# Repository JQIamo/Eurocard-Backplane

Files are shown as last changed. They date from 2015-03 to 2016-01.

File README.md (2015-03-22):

# Eurocard-Backplane

A customized backplane for the JQI Eurocard racks.

This repository also includes a "starter" schematic/board for compliant modules: `EurocardModule.*` Simply copy and paste this into your project folder (or re-save with a different name into your project), and you're off to the races!

## JQI Eurocard standard

We have made our backplane standard compliant with the Toptica backplane -- ie, Toptica modules should work in the JQI rack (and vice versa). However, double-check to make sure there aren't conflicting GPIO signal lines!

Compliant modules should follow the backplane standard (see link below to backplane pinout, or check out the starter schematic in this repository). Here are a few other guidlines that should be followed when designing new modules:

* You are responsible for regulating down from `+/-15V` to the voltages you need.
* De-couple your module from the backplane power traces (eg, with a ferrite bead); be careful about introducing additional noise.
* The standard power supply should provide ~ 7 (?) amps of current to the rack at both `+15V` and `-15V`
* If you need higher voltages, use the HV line.
* The backplane will be (!) equipped with a microcontroller and `WIZNET` ethernet adapter.
* SPI chip-select lines (`SPI_CS`) are routed to individual modules (ie, not tied together on the back plane). If you want to use a microcontroller, you can communicate with the backplane MCU this way. You can also use the I2C bus if you wish (`I2C_SDA` and `I2C_SCL`).
* There is a 5V stable reference, provided from an LM399H zener reference on the back plane.

**Resources**:

* [Backplane pinout](https://docs.google.com/spreadsheets/d/1GiwGvO8Z4_M1yfA_NvQcPyxT0hQa0t4iZVfY6wiVYis/edit?usp=sharing)
* ...

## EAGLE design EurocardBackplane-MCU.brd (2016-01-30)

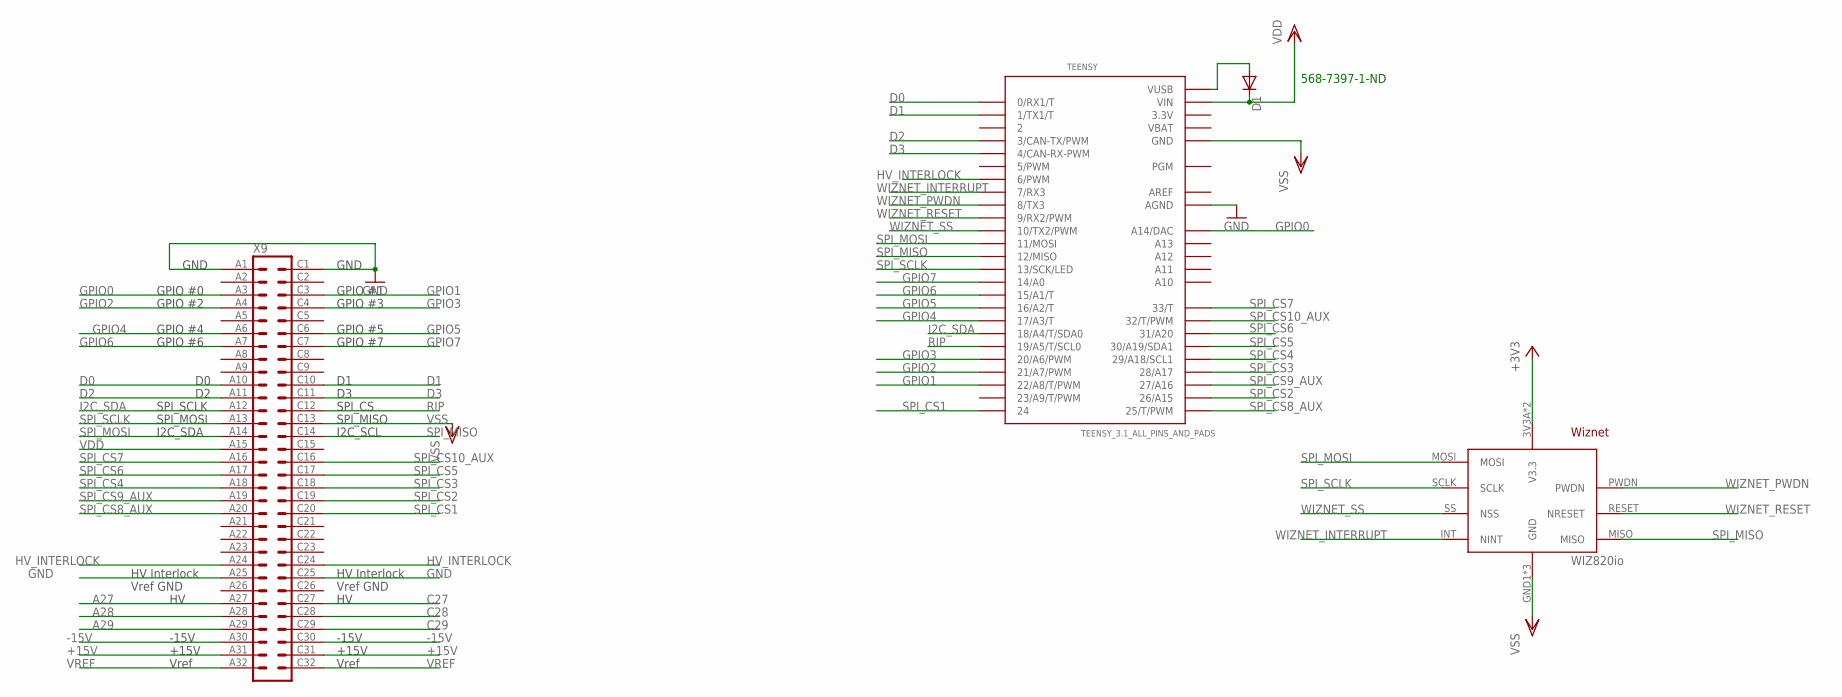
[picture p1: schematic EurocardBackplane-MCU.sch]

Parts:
D1: DIODE-SOD523; SOD523
TEENSY: TEENSY_3.1_ALL_PINS_AND_PADS; TEENSY_3.1_ALLPINS
U2: WIZ820IO; WIZNET
X9: VG64-PLAIN

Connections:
3.3V: TEENSY.3.3V, TEENSY.3.3V1 (3.3V), TEENSY.3.3V2 (3.3V)
+3V3: U2.3V3A (V3.3), U2.3V3B (V3.3)
+15V: X9.A31, X9.C31
-15V: X9.A30, X9.C30
A27: X9.A27
A28: X9.A28
A29: X9.A29
AREF: TEENSY.AREF
C27: X9.C27
C28: X9.C28
C29: X9.C29
D0: TEENSY.0 (0/RX1/T), X9.A10
D1: TEENSY.1 (1/TX1/T), X9.C10
D2: TEENSY.3 (3/CAN-TX/PWM), X9.A11
D3: TEENSY.4 (4/CAN-RX-PWM), X9.C11
GND: TEENSY.AGND, X9.A1, X9.A25, X9.C1, X9.C25
GPIO0: TEENSY.A14 (A14/DAC), X9.A3
GPIO1: TEENSY.22/A8 (22/A8/T/PWM), X9.C3
GPIO2: TEENSY.21/A7 (21/A7/PWM), X9.A4
GPIO3: TEENSY.20/A6 (20/A6/PWM), X9.C4
GPIO4: TEENSY.17/A3 (17/A3/T), X9.A6
GPIO5: TEENSY.16/A2 (16/A2/T), X9.C6
GPIO6: TEENSY.15/A1 (15/A1/T), X9.A7
GPIO7: TEENSY.14/A0, X9.C7
HV_INTERLOCK: TEENSY.6 (6/PWM), X9.A24, X9.C24
I2C_SDA: TEENSY.18/A4 (18/A4/T/SDA0), X9.A12
unnamed: D1.A, TEENSY.VUSB
RIP: TEENSY.19/A5 (19/A5/T/SCL0), X9.C12
SPI_CS1: TEENSY.24, X9.C20
SPI_CS2: TEENSY.26 (26/A15), X9.C19
SPI_CS3: TEENSY.28 (28/A17), X9.C18
SPI_CS4: TEENSY.29 (29/A18/SCL1), X9.A18
SPI_CS5: TEENSY.30 (30/A19/SDA1), X9.C17
SPI_CS6: TEENSY.31 (31/A20), X9.A17
SPI_CS7: TEENSY.33 (33/T), X9.A16
SPI_CS8_AUX: TEENSY.25 (25/T/PWM), X9.A20
SPI_CS9_AUX: TEENSY.27 (27/A16), X9.A19
SPI_CS10_AUX: TEENSY.32 (32/T/PWM), X9.C16
SPI_MISO: TEENSY.12 (12/MISO), U2.MISO, X9.C14
SPI_MOSI: TEENSY.11 (11/MOSI), U2.MOSI, X9.A14
SPI_SCLK: TEENSY.13 (13/SCK/LED), U2.SCLK, X9.A13
VBAT: TEENSY.VBAT
VDD: D1.C, TEENSY.VIN, X9.A15
VREF: X9.A32, X9.C32
VSS: TEENSY.GND, TEENSY.GND1 (GND), TEENSY.GND2 (GND), U2.GND1 (GND), U2.GND2 (GND), U2.GND3 (GND), X9.C13
WIZNET_INTERRUPT: TEENSY.7 (7/RX3), U2.INT (NINT)
WIZNET_PWDN: TEENSY.8 (8/TX3), U2.PWDN
WIZNET_RESET: TEENSY.9 (9/RX2/PWM), U2.RESET (NRESET)
WIZNET_SS: TEENSY.10 (10/TX2/PWM), U2.SS (NSS)

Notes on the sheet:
568-7397-1-ND

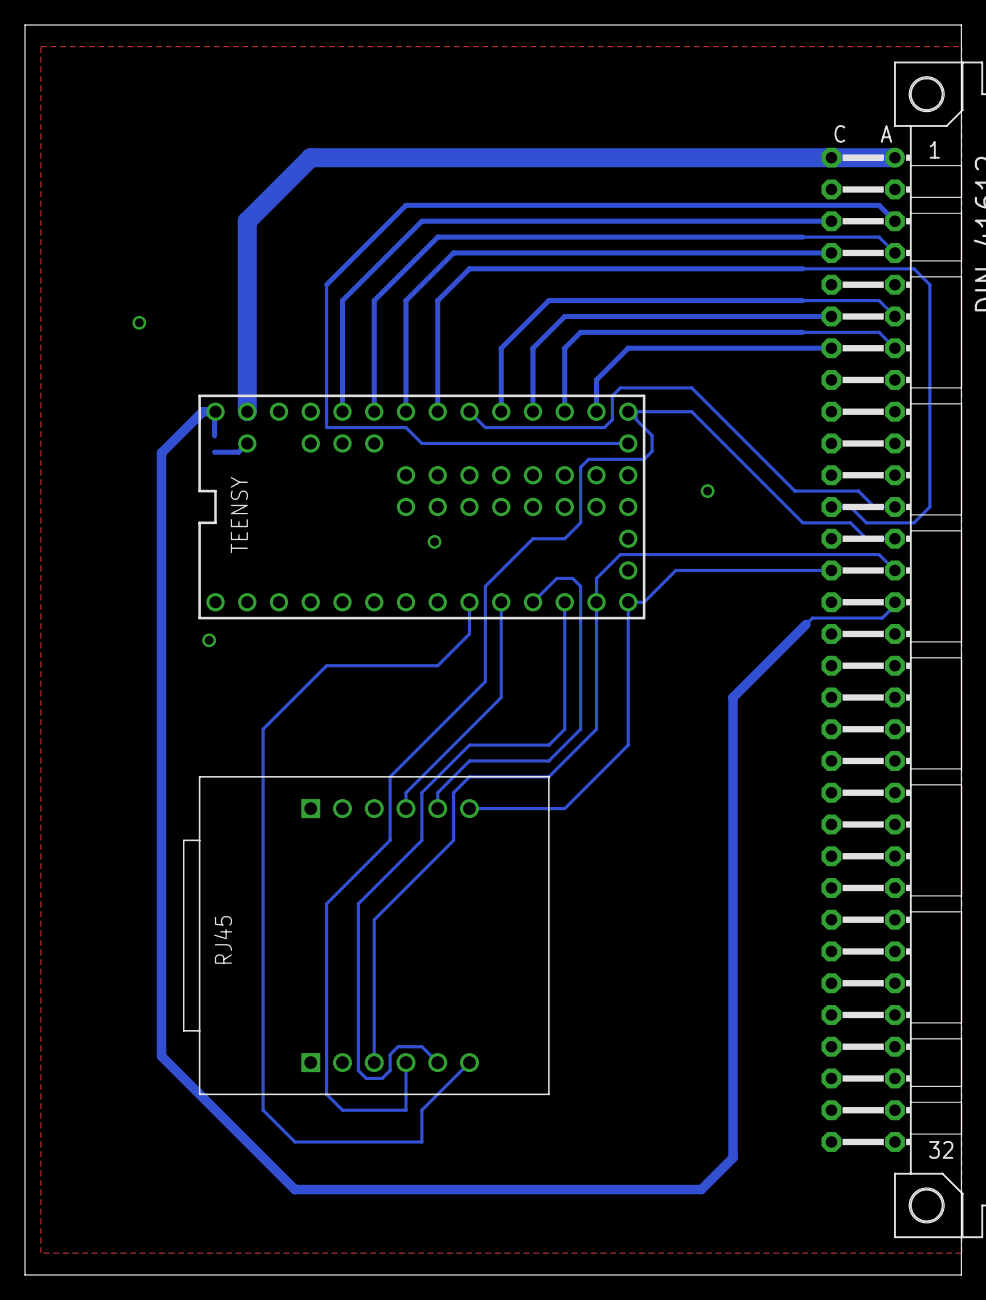
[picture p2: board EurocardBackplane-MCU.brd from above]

Board: 2 copper layers, 74.9 x 100.0 mm, 4 parts (1 on the bottom side), 41 nets.

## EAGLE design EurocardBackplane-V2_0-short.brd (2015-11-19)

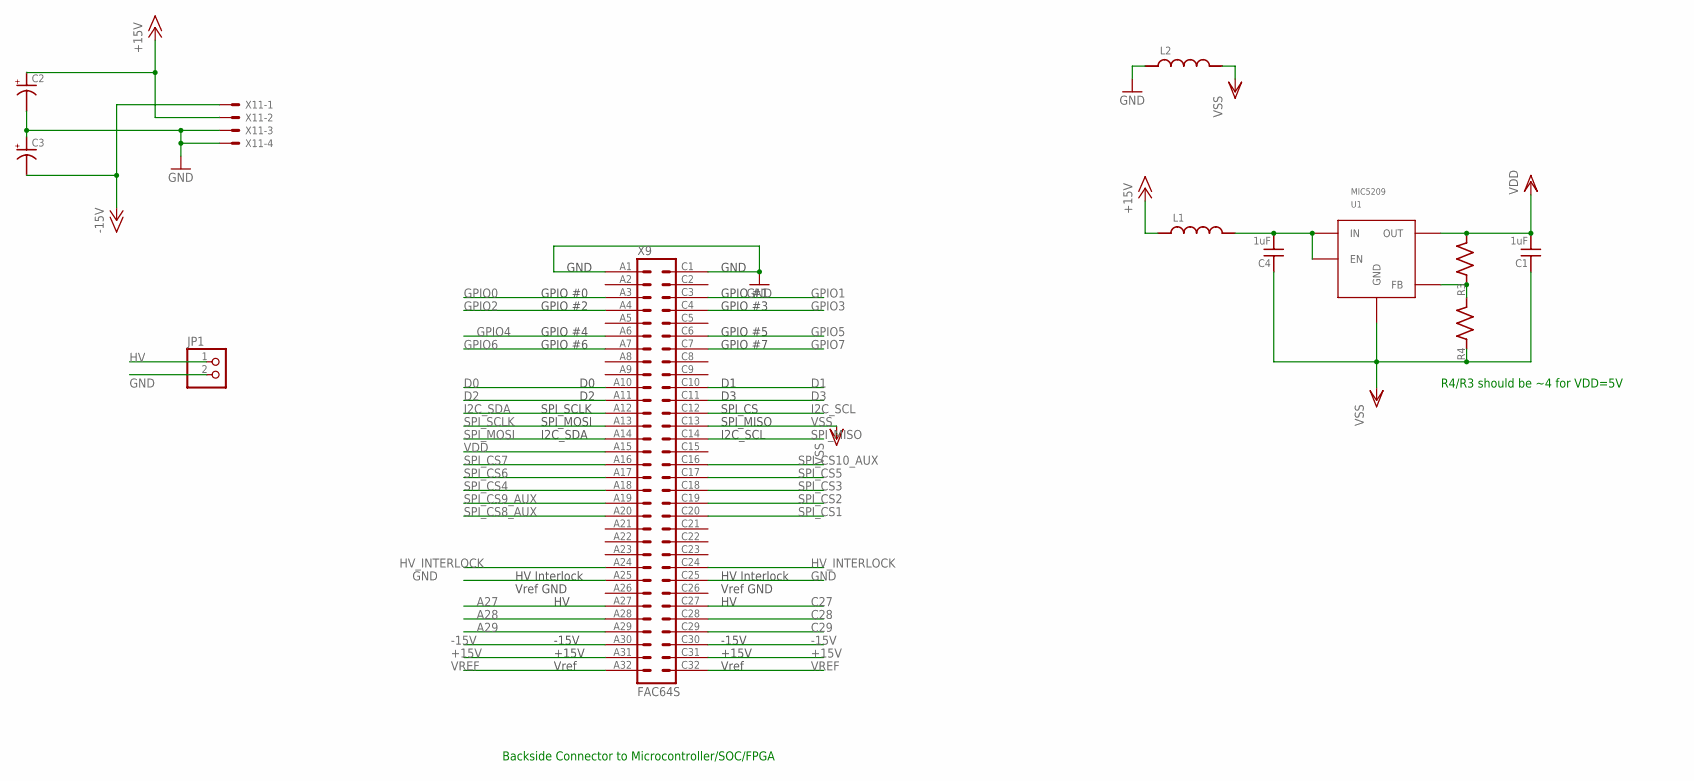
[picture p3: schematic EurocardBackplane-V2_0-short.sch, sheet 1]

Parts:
C1, C4: 1uF; C_MLCC_0603
C2, C3: C_POL_SMDF; PANASONIC_F
JP1: PINHD-1X2; 1X02
L1, L2: L_FERRITE_SMDLFERRITE_0805; R_0805
R3, R4: R_SMDR0603; R_0603
U1: MIC5209; TO263-5
X9: FAC64S
X11: 5566-4

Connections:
+15V: C2.+, L1.P$1 (1), X9.A31, X9.C31, X11.2; also elsewhere on the board
-15V: C3.-, X9.A30, X9.C30, X11.1; also elsewhere on the board
A27: X9.A27; also elsewhere on the board
A28: X9.A28; also elsewhere on the board
A29: X9.A29; also elsewhere on the board
C27: X9.C27; also elsewhere on the board
C28: X9.C28; also elsewhere on the board
C29: X9.C29; also elsewhere on the board
D0: X9.A10; also elsewhere on the board
D1: X9.C10; also elsewhere on the board
D2: X9.A11; also elsewhere on the board
D3: X9.C11; also elsewhere on the board
GND: C2.-, C3.+, JP1.2, L2.P$1 (1), X9.A1, X9.A25, X9.C1, X9.C25, X11.3, X11.4; also elsewhere on the board
GPIO0: X9.A3; also elsewhere on the board
GPIO1: X9.C3; also elsewhere on the board
GPIO2: X9.A4; also elsewhere on the board
GPIO3: X9.C4; also elsewhere on the board
GPIO4: X9.A6; also elsewhere on the board
GPIO5: X9.C6; also elsewhere on the board
GPIO6: X9.A7; also elsewhere on the board
GPIO7: X9.C7; also elsewhere on the board
HV: JP1.1; also elsewhere on the board
HV_INTERLOCK: X9.A24, X9.C24; also elsewhere on the board
I2C_SCL: X9.C12; also elsewhere on the board
I2C_SDA: X9.A12; also elsewhere on the board
unnamed: C4.P$2 (2), L1.P$2 (2), U1.1 (EN), U1.2 (IN)
unnamed: R3.P$1 (1), R4.P$2 (2), U1.5 (FB)
SPI_CS1: X9.C20
SPI_CS2: X9.C19
SPI_CS3: X9.C18
SPI_CS4: X9.A18
SPI_CS5: X9.C17
SPI_CS6: X9.A17; also elsewhere on the board
SPI_CS7: X9.A16; also elsewhere on the board
SPI_CS8_AUX: X9.A20
SPI_CS9_AUX: X9.A19
SPI_CS10_AUX: X9.C16; also elsewhere on the board
SPI_MISO: X9.C14; also elsewhere on the board
SPI_MOSI: X9.A14; also elsewhere on the board
SPI_SCLK: X9.A13; also elsewhere on the board
VDD: C1.P$2 (2), R3.P$2 (2), U1.4 (OUT), X9.A15; also elsewhere on the board
VREF: X9.A32, X9.C32; also elsewhere on the board
VSS: C1.P$1 (1), C4.P$1 (1), L2.P$2 (2), R4.P$1 (1), U1.3 (GND), U1.6 (GND), X9.C13; also elsewhere on the board

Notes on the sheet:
Backside Connector to Microcontroller/SOC/FPGA
R4/R3 should be ~4 for VDD=5V

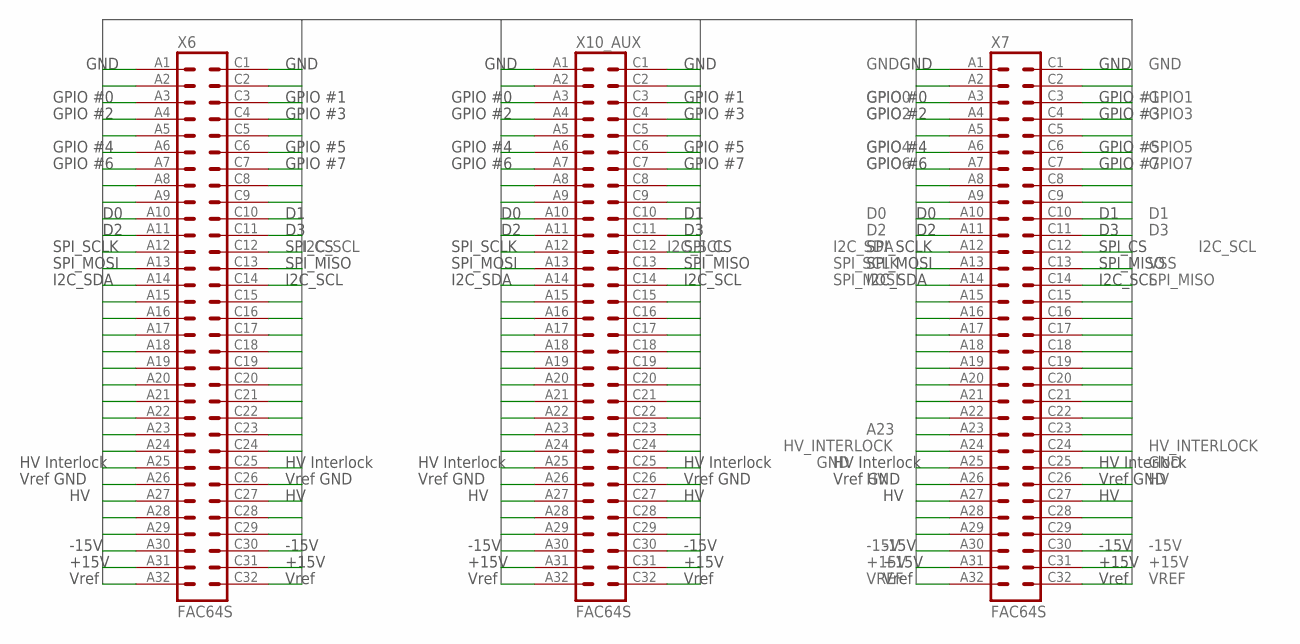
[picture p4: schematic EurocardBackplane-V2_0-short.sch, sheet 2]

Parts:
X6, X7, X10_AUX: FAC64S

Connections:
+15V: X6.A31, X6.C31, X7.A31, X7.C31, X10_AUX.A31, X10_AUX.C31; also elsewhere on the board
-15V: X6.A30, X6.C30, X7.A30, X7.C30, X10_AUX.A30, X10_AUX.C30; also elsewhere on the board
A2: X6.A2, X7.A2, X10_AUX.A2
A5: X6.A5, X7.A5, X10_AUX.A5
A8: X6.A8, X7.A8, X10_AUX.A8
A9: X6.A9, X7.A9, X10_AUX.A9
A16: X6.A16, X7.A16, X10_AUX.A16
A17: X6.A17, X7.A17, X10_AUX.A17
A18: X6.A18, X7.A18, X10_AUX.A18
A19: X6.A19, X7.A19, X10_AUX.A19
A20: X6.A20, X7.A20, X10_AUX.A20
A21: X6.A21, X7.A21, X10_AUX.A21
A22: X6.A22, X7.A22, X10_AUX.A22
A23: X6.A23, X7.A23, X10_AUX.A23
A27: X6.A27, X7.A27, X10_AUX.A27; also elsewhere on the board
A28: X6.A28, X7.A28, X10_AUX.A28; also elsewhere on the board
A29: X6.A29, X7.A29, X10_AUX.A29; also elsewhere on the board
C2: X6.C2, X7.C2, X10_AUX.C2
C5: X6.C5, X7.C5, X10_AUX.C5
C8: X6.C8, X7.C8, X10_AUX.C8
C9: X6.C9, X7.C9, X10_AUX.C9
C16: X6.C16, X7.C16, X10_AUX.C16
C17: X6.C17, X7.C17, X10_AUX.C17
C18: X6.C18, X7.C18, X10_AUX.C18
C19: X6.C19, X7.C19, X10_AUX.C19
C20: X6.C20, X7.C20, X10_AUX.C20
C21: X6.C21, X7.C21, X10_AUX.C21
C22: X6.C22, X7.C22, X10_AUX.C22
C23: X6.C23, X7.C23, X10_AUX.C23
C27: X6.C27, X7.C27, X10_AUX.C27; also elsewhere on the board
C28: X6.C28, X7.C28, X10_AUX.C28; also elsewhere on the board
C29: X6.C29, X7.C29, X10_AUX.C29; also elsewhere on the board
D0: X6.A10, X7.A10, X10_AUX.A10; also elsewhere on the board
D1: X6.C10, X7.C10, X10_AUX.C10; also elsewhere on the board
D2: X6.A11, X7.A11, X10_AUX.A11; also elsewhere on the board
D3: X6.C11, X7.C11, X10_AUX.C11; also elsewhere on the board
GND: X6.A1, X6.A25, X6.C1, X6.C25, X7.A1, X7.A25, X7.C1, X7.C25, X10_AUX.A1, X10_AUX.A25, X10_AUX.C1, X10_AUX.C25; also elsewhere on the board
GPIO0: X6.A3, X7.A3, X10_AUX.A3; also elsewhere on the board
GPIO1: X6.C3, X7.C3, X10_AUX.C3; also elsewhere on the board
GPIO2: X6.A4, X7.A4, X10_AUX.A4; also elsewhere on the board
GPIO3: X6.C4, X7.C4, X10_AUX.C4; also elsewhere on the board
GPIO4: X6.A6, X7.A6, X10_AUX.A6; also elsewhere on the board
GPIO5: X6.C6, X7.C6, X10_AUX.C6; also elsewhere on the board
GPIO6: X6.A7, X7.A7, X10_AUX.A7; also elsewhere on the board
GPIO7: X6.C7, X7.C7, X10_AUX.C7; also elsewhere on the board
HV: X6.A26, X6.C26, X7.A26, X7.C26, X10_AUX.A26, X10_AUX.C26; also elsewhere on the board
HV_INTERLOCK: X6.A24, X6.C24, X7.A24, X7.C24, X10_AUX.A24, X10_AUX.C24; also elsewhere on the board
I2C_SCL: X6.C12, X7.C12, X10_AUX.C12; also elsewhere on the board
I2C_SDA: X6.A12, X7.A12, X10_AUX.A12; also elsewhere on the board
SPI_CS6: X6.C15; also elsewhere on the board
SPI_CS7: X7.C15; also elsewhere on the board
SPI_CS10_AUX: X10_AUX.C15; also elsewhere on the board
SPI_MISO: X6.C14, X7.C14, X10_AUX.C14; also elsewhere on the board
SPI_MOSI: X6.A14, X7.A14, X10_AUX.A14; also elsewhere on the board
SPI_SCLK: X6.A13, X7.A13, X10_AUX.A13; also elsewhere on the board
VDD: X6.A15, X7.A15, X10_AUX.A15; also elsewhere on the board
VREF: X6.A32, X6.C32, X7.A32, X7.C32, X10_AUX.A32, X10_AUX.C32; also elsewhere on the board
VSS: X6.C13, X7.C13, X10_AUX.C13; also elsewhere on the board

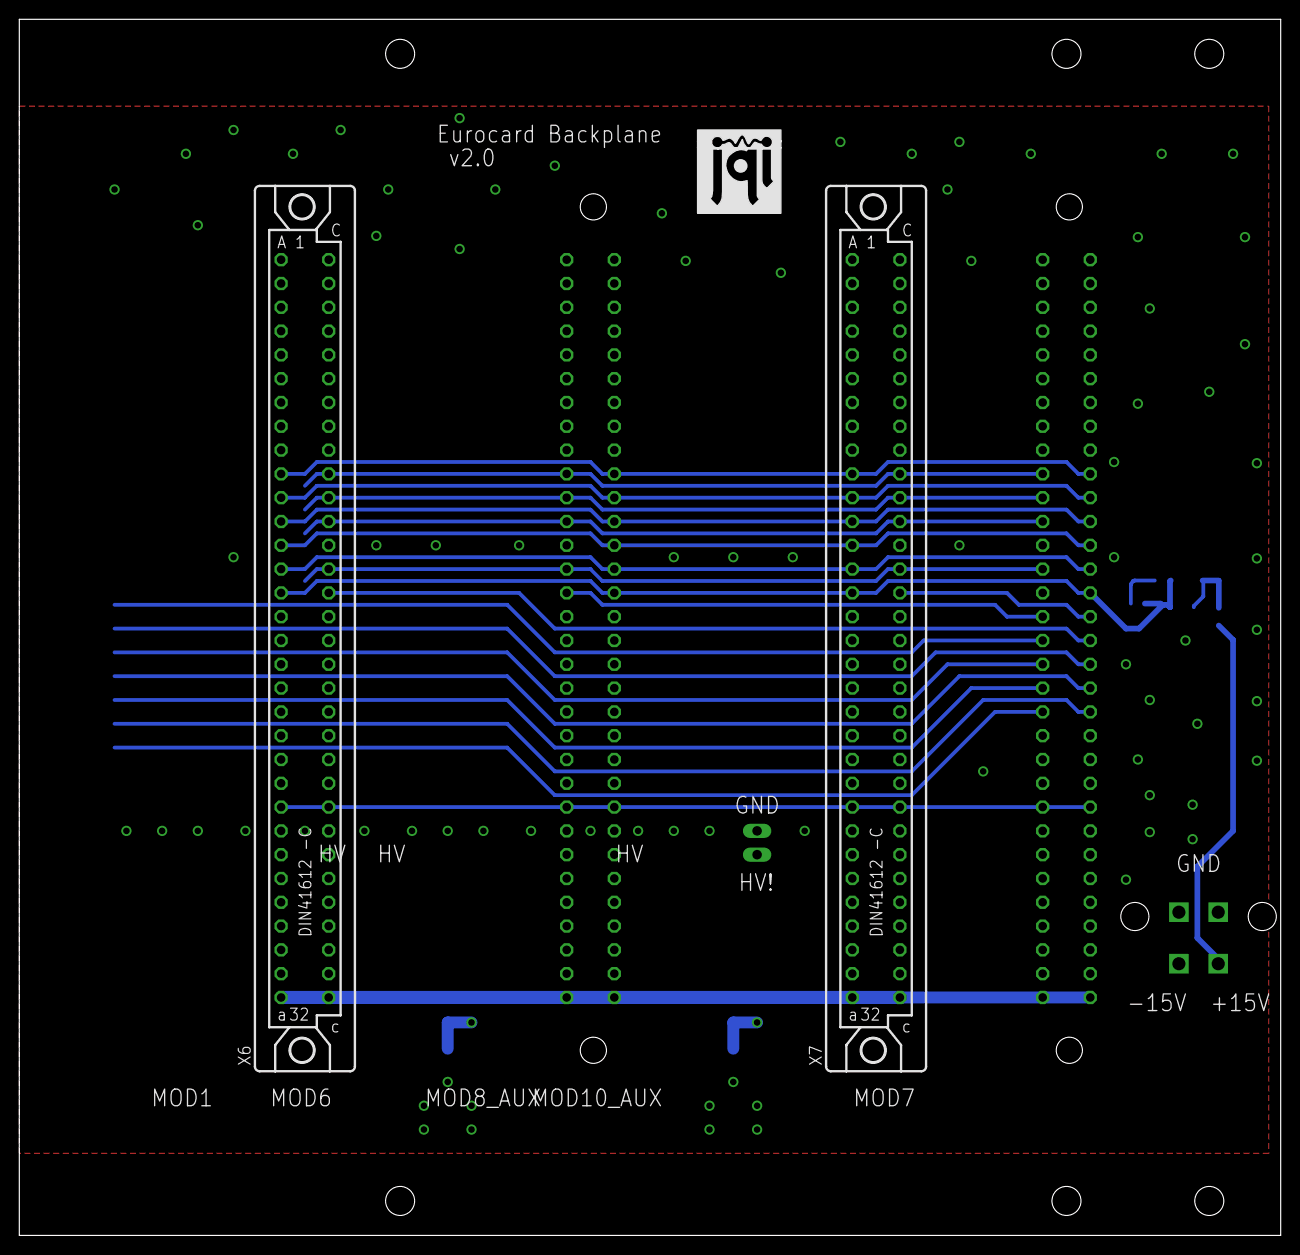
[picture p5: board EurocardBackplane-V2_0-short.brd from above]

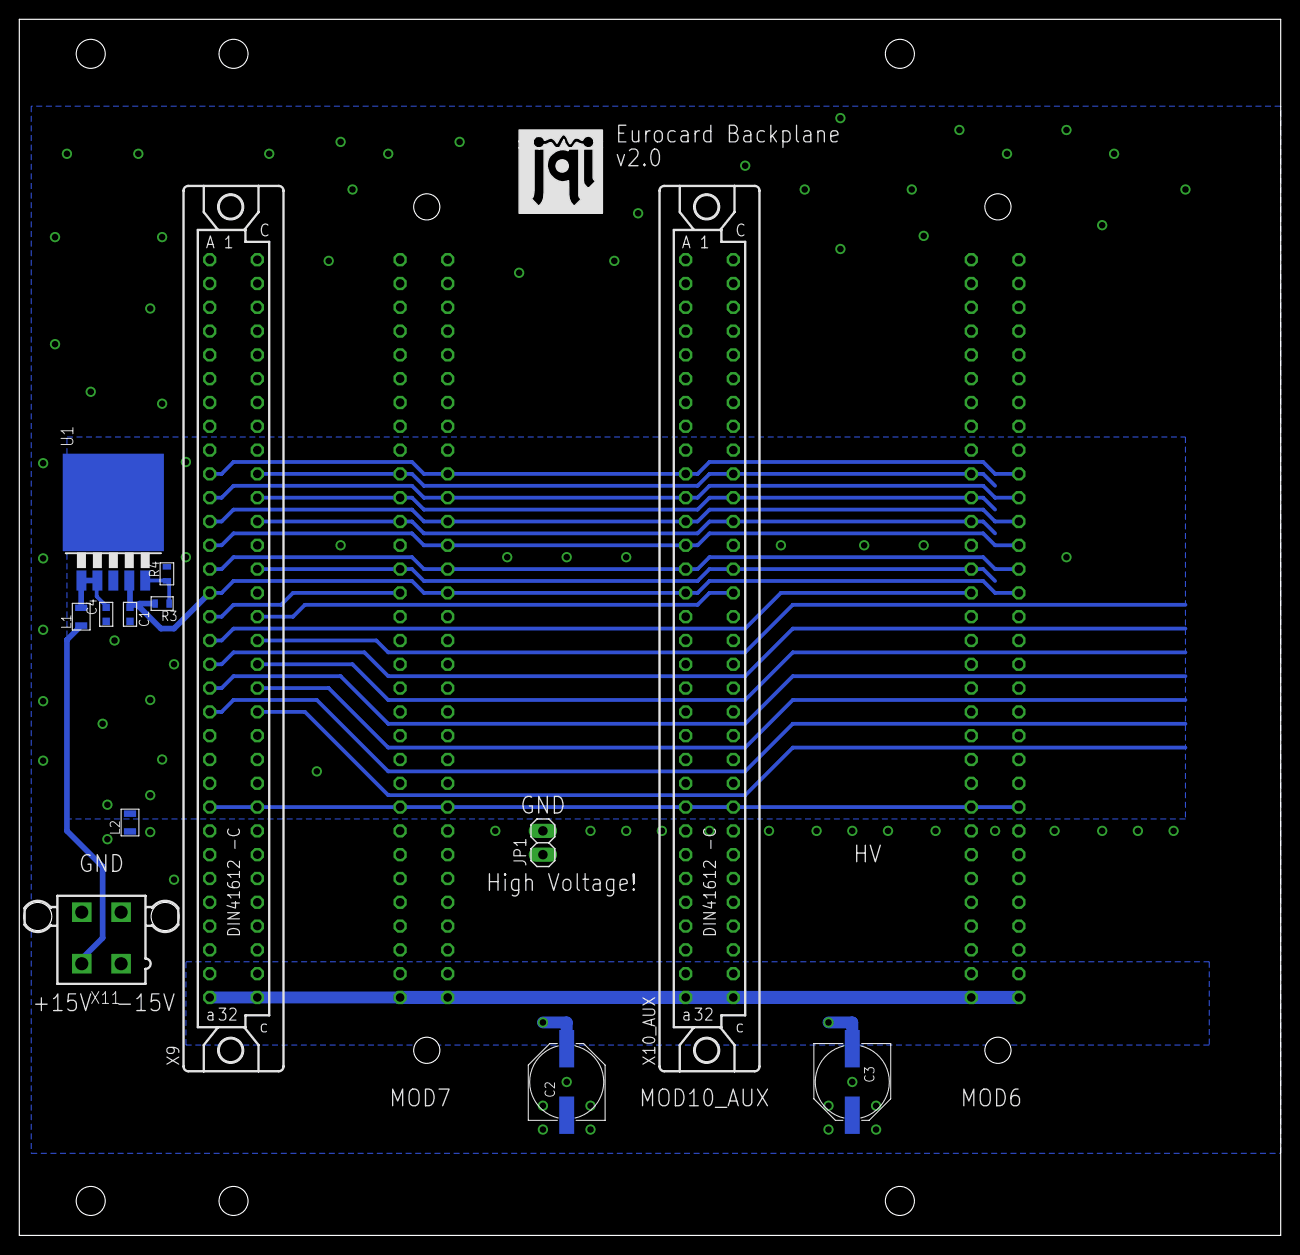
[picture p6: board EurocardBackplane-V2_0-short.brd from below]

Board: 4 copper layers, 134.6 x 129.8 mm, 18 parts (14 on the bottom side), 60 nets.

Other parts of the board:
U$1, U$4: JQI_LOGO_NEGATIVE-SILKSCREEN
U$2: BACKPLN-PROTO

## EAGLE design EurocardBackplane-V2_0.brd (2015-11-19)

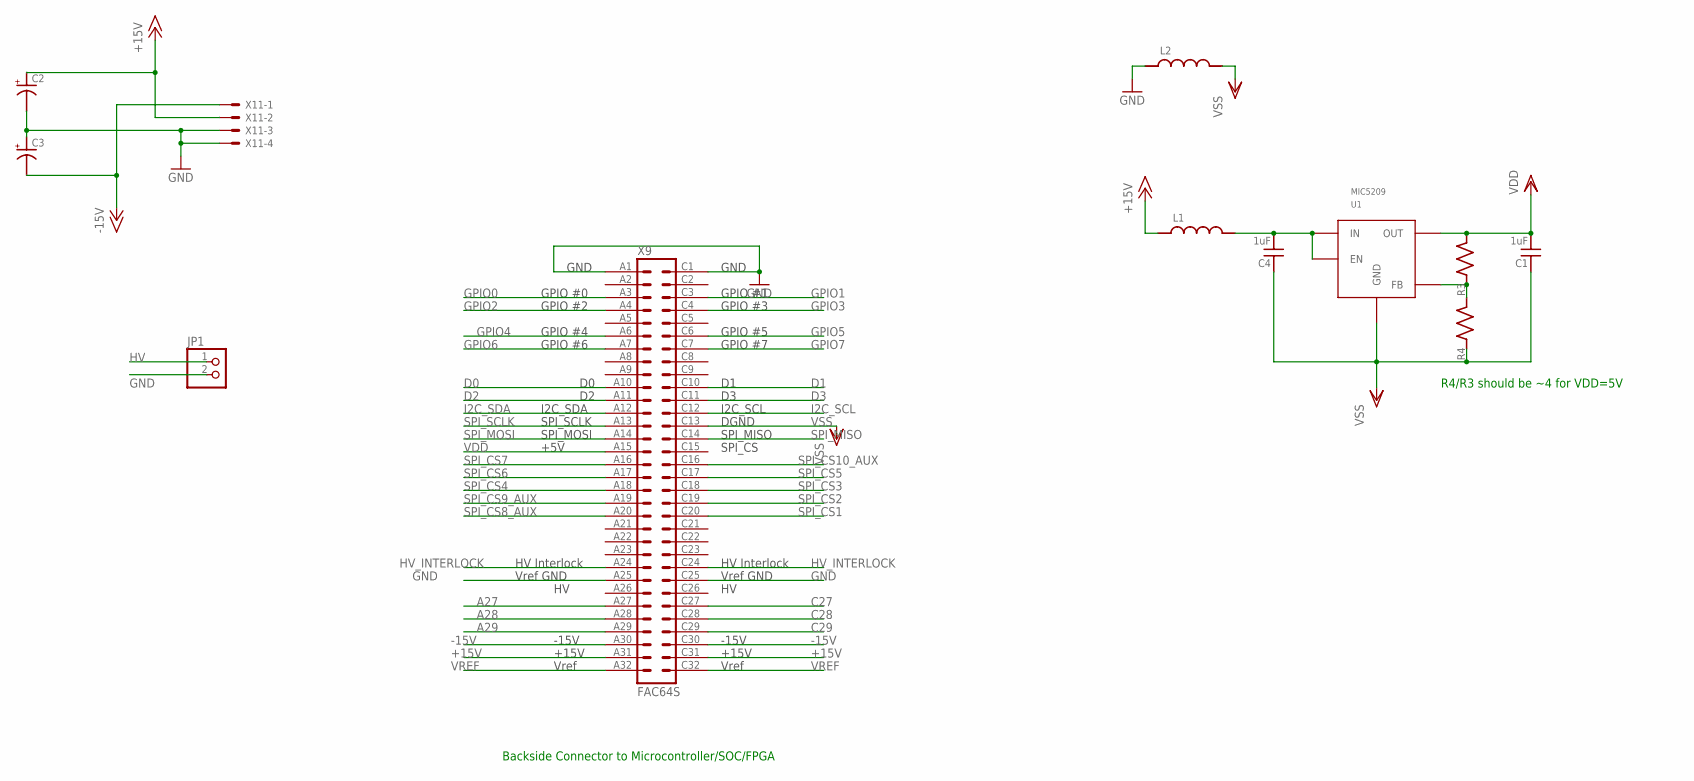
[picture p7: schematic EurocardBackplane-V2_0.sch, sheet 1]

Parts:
C1, C4: 1uF; C_MLCC_0603
C2, C3: C_POL_SMDF; PANASONIC_F
JP1: PINHD-1X2; 1X02
L1, L2: L_FERRITE_SMDLFERRITE_0805; R_0805
R3, R4: R_SMDR0603; R_0603
U1: MIC5209; TO263-5
X9: FAC64S
X11: 5566-4

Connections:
+15V: C2.+, L1.P$1 (1), X9.A31, X9.C31, X11.2; also elsewhere on the board
-15V: C3.-, X9.A30, X9.C30, X11.1; also elsewhere on the board
A27: X9.A27; also elsewhere on the board
A28: X9.A28; also elsewhere on the board
A29: X9.A29; also elsewhere on the board
C27: X9.C27; also elsewhere on the board
C28: X9.C28; also elsewhere on the board
C29: X9.C29; also elsewhere on the board
D0: X9.A10; also elsewhere on the board
D1: X9.C10; also elsewhere on the board
D2: X9.A11; also elsewhere on the board
D3: X9.C11; also elsewhere on the board
GND: C2.-, C3.+, JP1.2, L2.P$1 (1), X9.A1, X9.A25, X9.C1, X9.C25, X11.3, X11.4; also elsewhere on the board
GPIO0: X9.A3; also elsewhere on the board
GPIO1: X9.C3; also elsewhere on the board
GPIO2: X9.A4; also elsewhere on the board
GPIO3: X9.C4; also elsewhere on the board
GPIO4: X9.A6; also elsewhere on the board
GPIO5: X9.C6; also elsewhere on the board
GPIO6: X9.A7; also elsewhere on the board
GPIO7: X9.C7; also elsewhere on the board
HV: JP1.1; also elsewhere on the board
HV_INTERLOCK: X9.A24, X9.C24; also elsewhere on the board
I2C_SCL: X9.C12; also elsewhere on the board
I2C_SDA: X9.A12; also elsewhere on the board
unnamed: C4.P$2 (2), L1.P$2 (2), U1.1 (EN), U1.2 (IN)
unnamed: R3.P$1 (1), R4.P$2 (2), U1.5 (FB)
SPI_CS1: X9.C20; also elsewhere on the board
SPI_CS2: X9.C19; also elsewhere on the board
SPI_CS3: X9.C18; also elsewhere on the board
SPI_CS4: X9.A18; also elsewhere on the board
SPI_CS5: X9.C17; also elsewhere on the board
SPI_CS6: X9.A17; also elsewhere on the board
SPI_CS7: X9.A16; also elsewhere on the board
SPI_CS8_AUX: X9.A20; also elsewhere on the board
SPI_CS9_AUX: X9.A19; also elsewhere on the board
SPI_CS10_AUX: X9.C16; also elsewhere on the board
SPI_MISO: X9.C14; also elsewhere on the board
SPI_MOSI: X9.A14; also elsewhere on the board
SPI_SCLK: X9.A13; also elsewhere on the board
VDD: C1.P$2 (2), R3.P$2 (2), U1.4 (OUT), X9.A15; also elsewhere on the board
VREF: X9.A32, X9.C32; also elsewhere on the board
VSS: C1.P$1 (1), C4.P$1 (1), L2.P$2 (2), R4.P$1 (1), U1.3 (GND), U1.6 (GND), X9.C13; also elsewhere on the board

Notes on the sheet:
Backside Connector to Microcontroller/SOC/FPGA
R4/R3 should be ~4 for VDD=5V

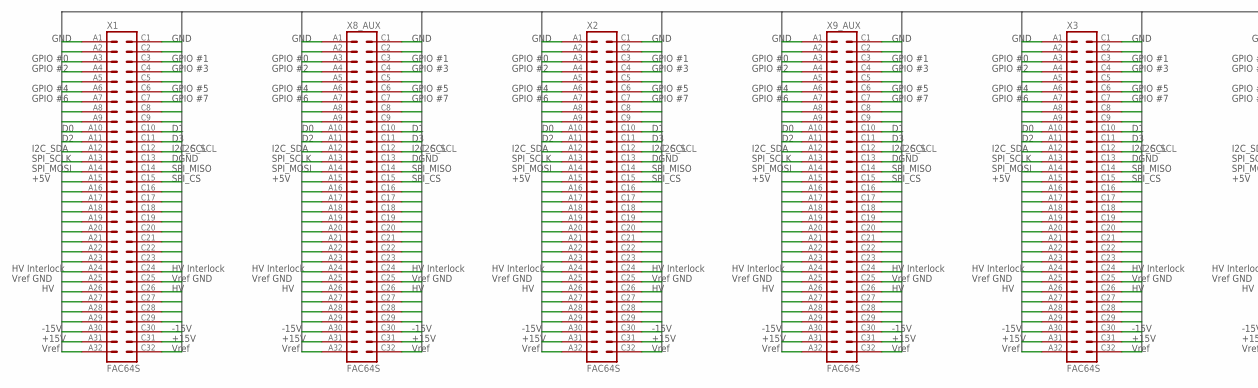
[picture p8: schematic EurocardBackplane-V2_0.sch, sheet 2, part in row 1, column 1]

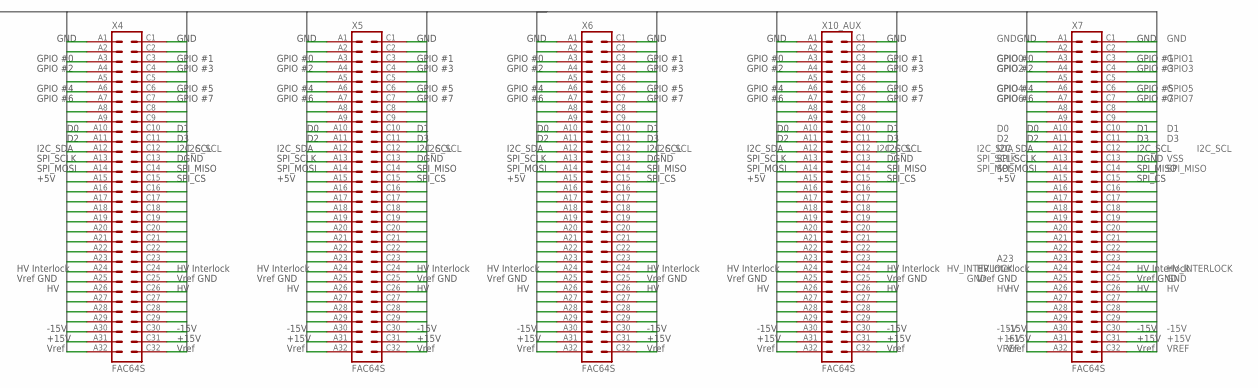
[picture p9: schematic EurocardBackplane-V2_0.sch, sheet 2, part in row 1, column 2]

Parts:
X1, X2, X3, X4, X5, X6, X7, X8_AUX, X9_AUX, X10_AUX: FAC64S

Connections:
+15V: X1.A31, X1.C31, X2.A31, X2.C31, X3.A31, X3.C31, X4.A31, X4.C31, X5.A31, X5.C31, X6.A31, X6.C31, X7.A31, X7.C31, X8_AUX.A31, X8_AUX.C31, X9_AUX.A31, X9_AUX.C31, X10_AUX.A31, X10_AUX.C31; also elsewhere on the board
-15V: X1.A30, X1.C30, X2.A30, X2.C30, X3.A30, X3.C30, X4.A30, X4.C30, X5.A30, X5.C30, X6.A30, X6.C30, X7.A30, X7.C30, X8_AUX.A30, X8_AUX.C30, X9_AUX.A30, X9_AUX.C30, X10_AUX.A30, X10_AUX.C30; also elsewhere on the board
A2: X1.A2, X2.A2, X3.A2, X4.A2, X5.A2, X6.A2, X7.A2, X8_AUX.A2, X9_AUX.A2, X10_AUX.A2
A5: X1.A5, X2.A5, X3.A5, X4.A5, X5.A5, X6.A5, X7.A5, X8_AUX.A5, X9_AUX.A5, X10_AUX.A5
A8: X1.A8, X2.A8, X3.A8, X4.A8, X5.A8, X6.A8, X7.A8, X8_AUX.A8, X9_AUX.A8, X10_AUX.A8
A9: X1.A9, X2.A9, X3.A9, X4.A9, X5.A9, X6.A9, X7.A9, X8_AUX.A9, X9_AUX.A9, X10_AUX.A9
A16: X1.A16, X2.A16, X3.A16, X4.A16, X5.A16, X6.A16, X7.A16, X8_AUX.A16, X9_AUX.A16, X10_AUX.A16
A17: X1.A17, X2.A17, X3.A17, X4.A17, X5.A17, X6.A17, X7.A17, X8_AUX.A17, X9_AUX.A17, X10_AUX.A17
A18: X1.A18, X2.A18, X3.A18, X4.A18, X5.A18, X6.A18, X7.A18, X8_AUX.A18, X9_AUX.A18, X10_AUX.A18
A19: X1.A19, X2.A19, X3.A19, X4.A19, X5.A19, X6.A19, X7.A19, X8_AUX.A19, X9_AUX.A19, X10_AUX.A19
A20: X1.A20, X2.A20, X3.A20, X4.A20, X5.A20, X6.A20, X7.A20, X8_AUX.A20, X9_AUX.A20, X10_AUX.A20
A21: X1.A21, X2.A21, X3.A21, X4.A21, X5.A21, X6.A21, X7.A21, X8_AUX.A21, X9_AUX.A21, X10_AUX.A21
A22: X1.A22, X2.A22, X3.A22, X4.A22, X5.A22, X6.A22, X7.A22, X8_AUX.A22, X9_AUX.A22, X10_AUX.A22
A23: X1.A23, X2.A23, X3.A23, X4.A23, X5.A23, X6.A23, X7.A23, X8_AUX.A23, X9_AUX.A23, X10_AUX.A23
A27: X1.A27, X2.A27, X3.A27, X4.A27, X5.A27, X6.A27, X7.A27, X8_AUX.A27, X9_AUX.A27, X10_AUX.A27; also elsewhere on the board
A28: X1.A28, X2.A28, X3.A28, X4.A28, X5.A28, X6.A28, X7.A28, X8_AUX.A28, X9_AUX.A28, X10_AUX.A28; also elsewhere on the board
A29: X1.A29, X2.A29, X3.A29, X4.A29, X5.A29, X6.A29, X7.A29, X8_AUX.A29, X9_AUX.A29, X10_AUX.A29; also elsewhere on the board
C2: X1.C2, X2.C2, X3.C2, X4.C2, X5.C2, X6.C2, X7.C2, X8_AUX.C2, X9_AUX.C2, X10_AUX.C2
C5: X1.C5, X2.C5, X3.C5, X4.C5, X5.C5, X6.C5, X7.C5, X8_AUX.C5, X9_AUX.C5, X10_AUX.C5
C8: X1.C8, X2.C8, X3.C8, X4.C8, X5.C8, X6.C8, X7.C8, X8_AUX.C8, X9_AUX.C8, X10_AUX.C8
C9: X1.C9, X2.C9, X3.C9, X4.C9, X5.C9, X6.C9, X7.C9, X8_AUX.C9, X9_AUX.C9, X10_AUX.C9
C16: X1.C16, X2.C16, X3.C16, X4.C16, X5.C16, X6.C16, X7.C16, X8_AUX.C16, X9_AUX.C16, X10_AUX.C16
C17: X1.C17, X2.C17, X3.C17, X4.C17, X5.C17, X6.C17, X7.C17, X8_AUX.C17, X9_AUX.C17, X10_AUX.C17
C18: X1.C18, X2.C18, X3.C18, X4.C18, X5.C18, X6.C18, X7.C18, X8_AUX.C18, X9_AUX.C18, X10_AUX.C18
C19: X1.C19, X2.C19, X3.C19, X4.C19, X5.C19, X6.C19, X7.C19, X8_AUX.C19, X9_AUX.C19, X10_AUX.C19
C20: X1.C20, X2.C20, X3.C20, X4.C20, X5.C20, X6.C20, X7.C20, X8_AUX.C20, X9_AUX.C20, X10_AUX.C20
C21: X1.C21, X2.C21, X3.C21, X4.C21, X5.C21, X6.C21, X7.C21, X8_AUX.C21, X9_AUX.C21, X10_AUX.C21
C22: X1.C22, X2.C22, X3.C22, X4.C22, X5.C22, X6.C22, X7.C22, X8_AUX.C22, X9_AUX.C22, X10_AUX.C22
C23: X1.C23, X2.C23, X3.C23, X4.C23, X5.C23, X6.C23, X7.C23, X8_AUX.C23, X9_AUX.C23, X10_AUX.C23
C27: X1.C27, X2.C27, X3.C27, X4.C27, X5.C27, X6.C27, X7.C27, X8_AUX.C27, X9_AUX.C27, X10_AUX.C27; also elsewhere on the board
C28: X1.C28, X2.C28, X3.C28, X4.C28, X5.C28, X6.C28, X7.C28, X8_AUX.C28, X9_AUX.C28, X10_AUX.C28; also elsewhere on the board
C29: X1.C29, X2.C29, X3.C29, X4.C29, X5.C29, X6.C29, X7.C29, X8_AUX.C29, X9_AUX.C29, X10_AUX.C29; also elsewhere on the board
D0: X1.A10, X2.A10, X3.A10, X4.A10, X5.A10, X6.A10, X7.A10, X8_AUX.A10, X9_AUX.A10, X10_AUX.A10; also elsewhere on the board
D1: X1.C10, X2.C10, X3.C10, X4.C10, X5.C10, X6.C10, X7.C10, X8_AUX.C10, X9_AUX.C10, X10_AUX.C10; also elsewhere on the board
D2: X1.A11, X2.A11, X3.A11, X4.A11, X5.A11, X6.A11, X7.A11, X8_AUX.A11, X9_AUX.A11, X10_AUX.A11; also elsewhere on the board
D3: X1.C11, X2.C11, X3.C11, X4.C11, X5.C11, X6.C11, X7.C11, X8_AUX.C11, X9_AUX.C11, X10_AUX.C11; also elsewhere on the board
GND: X1.A1, X1.A25, X1.C1, X1.C25, X2.A1, X2.A25, X2.C1, X2.C25, X3.A1, X3.A25, X3.C1, X3.C25, X4.A1, X4.A25, X4.C1, X4.C25, X5.A1, X5.A25, X5.C1, X5.C25, X6.A1, X6.A25, X6.C1, X6.C25, X7.A1, X7.A25, X7.C1, X7.C25, X8_AUX.A1, X8_AUX.A25, X8_AUX.C1, X8_AUX.C25, X9_AUX.A1, X9_AUX.A25, X9_AUX.C1, X9_AUX.C25, X10_AUX.A1, X10_AUX.A25, X10_AUX.C1, X10_AUX.C25; also elsewhere on the board
GPIO0: X1.A3, X2.A3, X3.A3, X4.A3, X5.A3, X6.A3, X7.A3, X8_AUX.A3, X9_AUX.A3, X10_AUX.A3; also elsewhere on the board
GPIO1: X1.C3, X2.C3, X3.C3, X4.C3, X5.C3, X6.C3, X7.C3, X8_AUX.C3, X9_AUX.C3, X10_AUX.C3; also elsewhere on the board
GPIO2: X1.A4, X2.A4, X3.A4, X4.A4, X5.A4, X6.A4, X7.A4, X8_AUX.A4, X9_AUX.A4, X10_AUX.A4; also elsewhere on the board
GPIO3: X1.C4, X2.C4, X3.C4, X4.C4, X5.C4, X6.C4, X7.C4, X8_AUX.C4, X9_AUX.C4, X10_AUX.C4; also elsewhere on the board
GPIO4: X1.A6, X2.A6, X3.A6, X4.A6, X5.A6, X6.A6, X7.A6, X8_AUX.A6, X9_AUX.A6, X10_AUX.A6; also elsewhere on the board
GPIO5: X1.C6, X2.C6, X3.C6, X4.C6, X5.C6, X6.C6, X7.C6, X8_AUX.C6, X9_AUX.C6, X10_AUX.C6; also elsewhere on the board
GPIO6: X1.A7, X2.A7, X3.A7, X4.A7, X5.A7, X6.A7, X7.A7, X8_AUX.A7, X9_AUX.A7, X10_AUX.A7; also elsewhere on the board
GPIO7: X1.C7, X2.C7, X3.C7, X4.C7, X5.C7, X6.C7, X7.C7, X8_AUX.C7, X9_AUX.C7, X10_AUX.C7; also elsewhere on the board
HV: X1.A26, X1.C26, X2.A26, X2.C26, X3.A26, X3.C26, X4.A26, X4.C26, X5.A26, X5.C26, X6.A26, X6.C26, X7.A26, X7.C26, X8_AUX.A26, X8_AUX.C26, X9_AUX.A26, X9_AUX.C26, X10_AUX.A26, X10_AUX.C26; also elsewhere on the board
HV_INTERLOCK: X1.A24, X1.C24, X2.A24, X2.C24, X3.A24, X3.C24, X4.A24, X4.C24, X5.A24, X5.C24, X6.A24, X6.C24, X7.A24, X7.C24, X8_AUX.A24, X8_AUX.C24, X9_AUX.A24, X9_AUX.C24, X10_AUX.A24, X10_AUX.C24; also elsewhere on the board
I2C_SCL: X1.C12, X2.C12, X3.C12, X4.C12, X5.C12, X6.C12, X7.C12, X8_AUX.C12, X9_AUX.C12, X10_AUX.C12; also elsewhere on the board
I2C_SDA: X1.A12, X2.A12, X3.A12, X4.A12, X5.A12, X6.A12, X7.A12, X8_AUX.A12, X9_AUX.A12, X10_AUX.A12; also elsewhere on the board
SPI_CS1: X1.C15; also elsewhere on the board
SPI_CS2: X2.C15; also elsewhere on the board
SPI_CS3: X3.C15; also elsewhere on the board
SPI_CS4: X4.C15; also elsewhere on the board
SPI_CS5: X5.C15; also elsewhere on the board
SPI_CS6: X6.C15; also elsewhere on the board
SPI_CS7: X7.C15; also elsewhere on the board
SPI_CS8_AUX: X8_AUX.C15; also elsewhere on the board
SPI_CS9_AUX: X9_AUX.C15; also elsewhere on the board
SPI_CS10_AUX: X10_AUX.C15; also elsewhere on the board
SPI_MISO: X1.C14, X2.C14, X3.C14, X4.C14, X5.C14, X6.C14, X7.C14, X8_AUX.C14, X9_AUX.C14, X10_AUX.C14; also elsewhere on the board
SPI_MOSI: X1.A14, X2.A14, X3.A14, X4.A14, X5.A14, X6.A14, X7.A14, X8_AUX.A14, X9_AUX.A14, X10_AUX.A14; also elsewhere on the board
SPI_SCLK: X1.A13, X2.A13, X3.A13, X4.A13, X5.A13, X6.A13, X7.A13, X8_AUX.A13, X9_AUX.A13, X10_AUX.A13; also elsewhere on the board
VDD: X1.A15, X2.A15, X3.A15, X4.A15, X5.A15, X6.A15, X7.A15, X8_AUX.A15, X9_AUX.A15, X10_AUX.A15; also elsewhere on the board
VREF: X1.A32, X1.C32, X2.A32, X2.C32, X3.A32, X3.C32, X4.A32, X4.C32, X5.A32, X5.C32, X6.A32, X6.C32, X7.A32, X7.C32, X8_AUX.A32, X8_AUX.C32, X9_AUX.A32, X9_AUX.C32, X10_AUX.A32, X10_AUX.C32; also elsewhere on the board
VSS: X1.C13, X2.C13, X3.C13, X4.C13, X5.C13, X6.C13, X7.C13, X8_AUX.C13, X9_AUX.C13, X10_AUX.C13; also elsewhere on the board

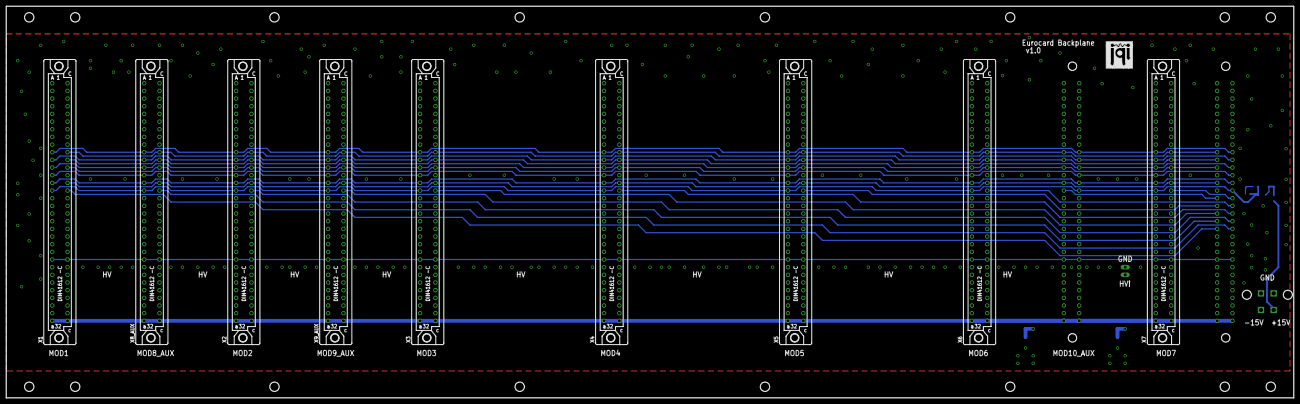
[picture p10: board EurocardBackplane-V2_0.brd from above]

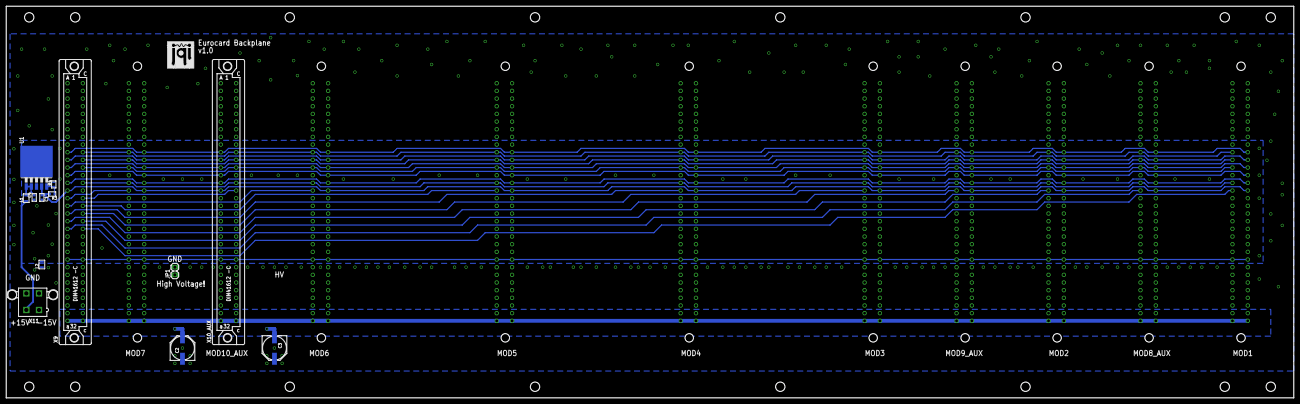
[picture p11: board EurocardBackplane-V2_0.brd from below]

Board: 4 copper layers, 426.7 x 129.8 mm, 25 parts (14 on the bottom side), 67 nets.

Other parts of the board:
U$1, U$4: JQI_LOGO_NEGATIVE-SILKSCREEN
U$3: BACKPLANE

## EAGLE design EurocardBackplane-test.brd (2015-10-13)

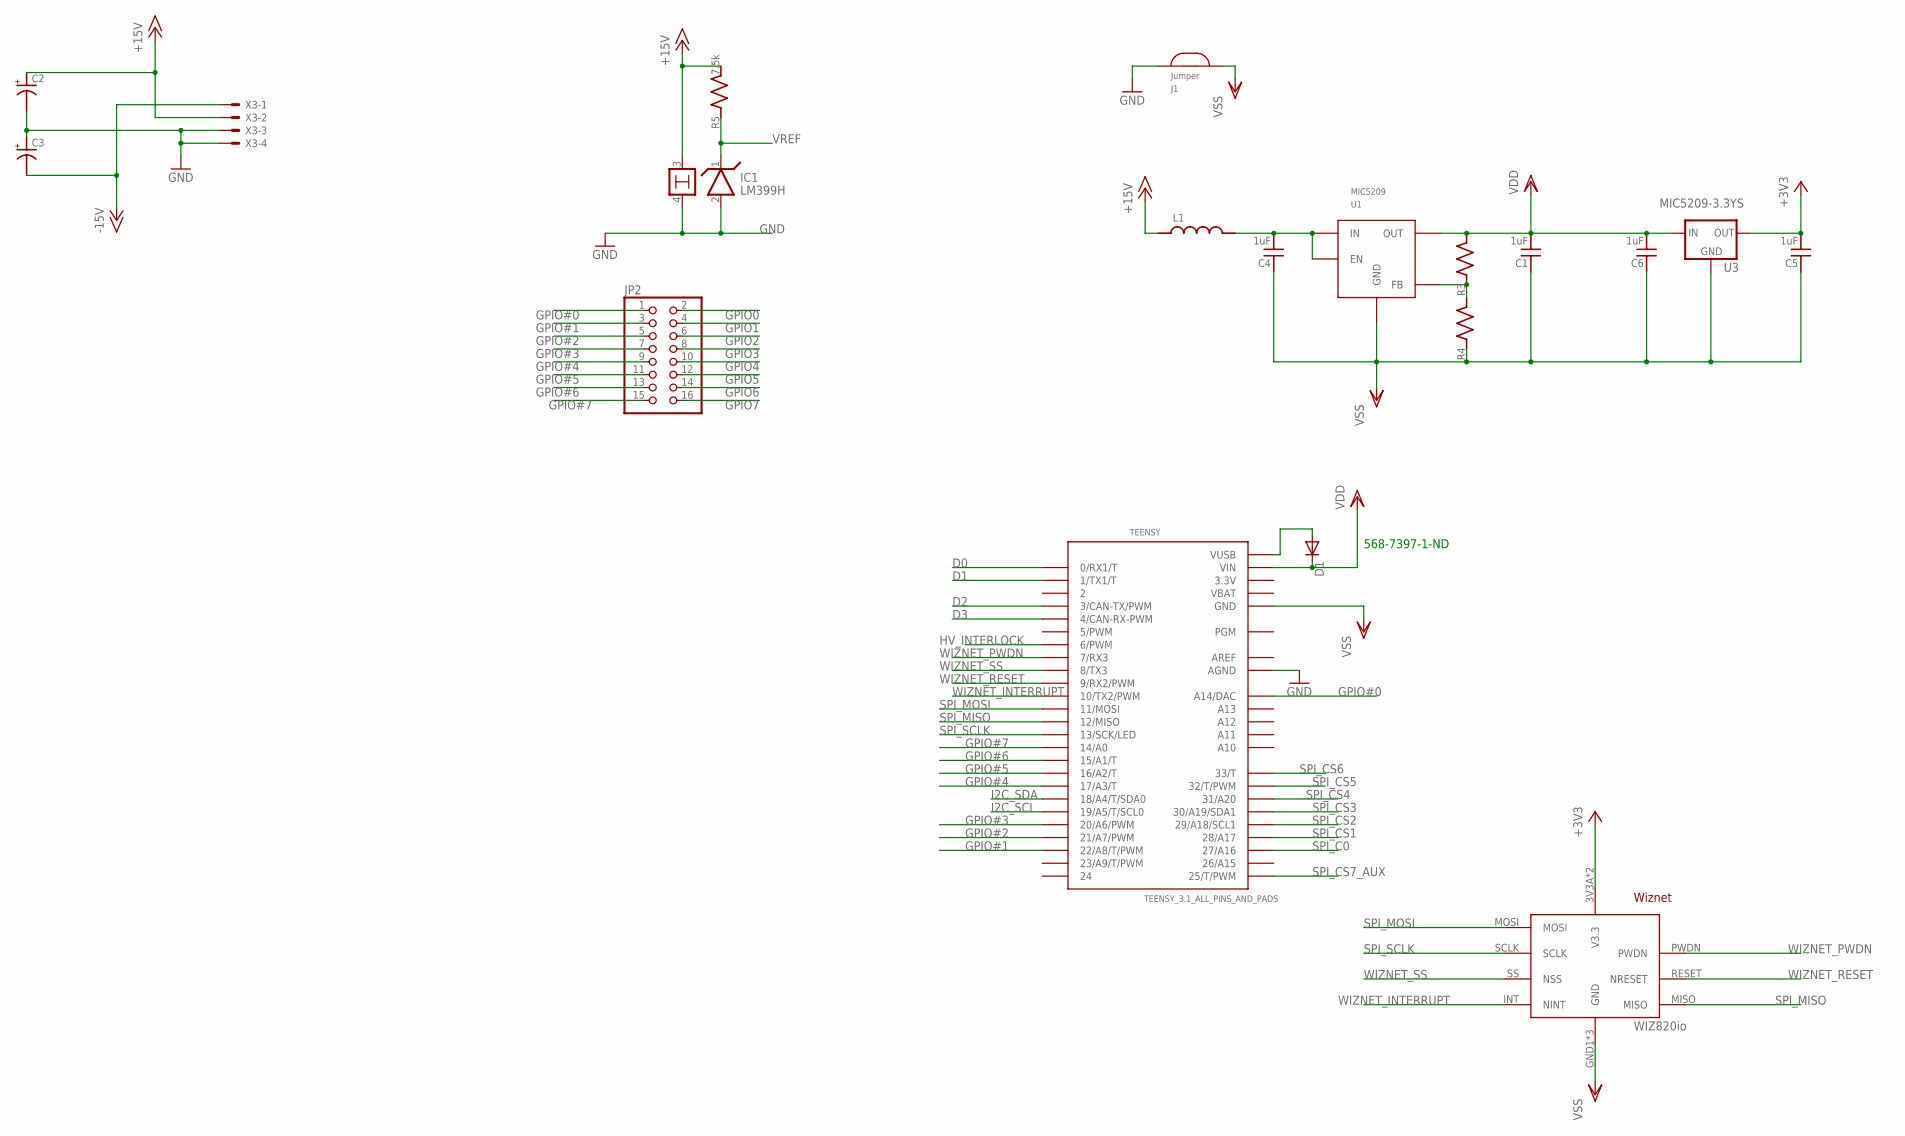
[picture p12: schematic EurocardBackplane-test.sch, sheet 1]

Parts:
C1, C4, C5, C6: 1uF; C_MLCC_0603
C2, C3: C_POL_SMDF; PANASONIC_F
D1: DIODE-SOD523; SOD523
IC1: LM399H; TO39/4
J1: JUMPER; JUMP
JP2: PINHD-2X8; 2X08
L1: L_FERRITE_SMDLFERRITE_0805; R_0805
R3, R4: R_SMDR0603; R_0603
R5: 7.5k; R_0603
TEENSY: TEENSY_3.1_ALL_PINS_AND_PADS; TEENSY_3.1_ALLPINS
U1: MIC5209; TO263-5
U2: WIZ820IO; WIZNET
U3: MIC5209-3.3YS; SOT223-S
X3: 5566-4

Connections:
3.3V: TEENSY.3.3V, TEENSY.3.3V1 (3.3V), TEENSY.3.3V2 (3.3V)
+3V3: C5.P$2 (2), U2.3V3A (V3.3), U2.3V3B (V3.3), U3.3 (OUT)
+15V: C2.+, IC1.3, L1.P$1 (1), R5.P$2 (2), X3.2; also elsewhere on the board
-15V: C3.-, X3.1; also elsewhere on the board
AREF: TEENSY.AREF
D0: TEENSY.0 (0/RX1/T); also elsewhere on the board
D1: TEENSY.1 (1/TX1/T); also elsewhere on the board
D2: TEENSY.3 (3/CAN-TX/PWM); also elsewhere on the board
D3: TEENSY.4 (4/CAN-RX-PWM); also elsewhere on the board
GND: C2.-, C3.+, IC1.2, IC1.4, J1.P$2, TEENSY.AGND, X3.3, X3.4; also elsewhere on the board
GPIO0: JP2.2; also elsewhere on the board
GPIO1: JP2.4; also elsewhere on the board
GPIO2: JP2.6; also elsewhere on the board
GPIO3: JP2.8; also elsewhere on the board
GPIO4: JP2.10; also elsewhere on the board
GPIO5: JP2.12; also elsewhere on the board
GPIO6: JP2.14; also elsewhere on the board
GPIO7: JP2.16; also elsewhere on the board
GPIO#0: JP2.1, TEENSY.A14 (A14/DAC)
GPIO#1: JP2.3, TEENSY.22/A8 (22/A8/T/PWM)
GPIO#2: JP2.5, TEENSY.21/A7 (21/A7/PWM)
GPIO#3: JP2.7, TEENSY.20/A6 (20/A6/PWM)
GPIO#4: JP2.9, TEENSY.17/A3 (17/A3/T)
GPIO#5: JP2.11, TEENSY.16/A2 (16/A2/T)
GPIO#6: JP2.13, TEENSY.15/A1 (15/A1/T)
GPIO#7: JP2.15, TEENSY.14/A0
HV_INTERLOCK: TEENSY.6 (6/PWM); also elsewhere on the board
I2C_SCL: TEENSY.19/A5 (19/A5/T/SCL0); also elsewhere on the board
I2C_SDA: TEENSY.18/A4 (18/A4/T/SDA0); also elsewhere on the board
unnamed: C4.P$2 (2), L1.P$2 (2), U1.1 (EN), U1.2 (IN)
unnamed: D1.A, TEENSY.VUSB
unnamed: R3.P$1 (1), R4.P$2 (2), U1.5 (FB)
SPI_C0: TEENSY.27 (27/A16)
SPI_CS1: TEENSY.28 (28/A17)
SPI_CS2: TEENSY.29 (29/A18/SCL1)
SPI_CS3: TEENSY.30 (30/A19/SDA1)
SPI_CS4: TEENSY.31 (31/A20)
SPI_CS5: TEENSY.32 (32/T/PWM); also elsewhere on the board
SPI_CS6: TEENSY.33 (33/T); also elsewhere on the board
SPI_CS7_AUX: TEENSY.25 (25/T/PWM); also elsewhere on the board
SPI_MISO: TEENSY.12 (12/MISO), U2.MISO; also elsewhere on the board
SPI_MOSI: TEENSY.11 (11/MOSI), U2.MOSI; also elsewhere on the board
SPI_SCLK: TEENSY.13 (13/SCK/LED), U2.SCLK; also elsewhere on the board
VBAT: TEENSY.VBAT
VDD: C1.P$2 (2), C6.P$2 (2), D1.C, R3.P$2 (2), TEENSY.VIN, U1.4 (OUT), U3.1 (IN)
VREF: IC1.1, R5.P$1 (1); also elsewhere on the board
VSS: C1.P$1 (1), C4.P$1 (1), C5.P$1 (1), C6.P$1 (1), J1.P$1, R4.P$1 (1), TEENSY.GND, TEENSY.GND1 (GND), TEENSY.GND2 (GND), U1.3 (GND), U1.6 (GND), U2.GND1 (GND), U2.GND2 (GND), U2.GND3 (GND), U3.2 (GND), U3.4 (GND)
WIZNET_INTERRUPT: TEENSY.10 (10/TX2/PWM), U2.INT (NINT)
WIZNET_PWDN: TEENSY.7 (7/RX3), U2.PWDN
WIZNET_RESET: TEENSY.9 (9/RX2/PWM), U2.RESET (NRESET)
WIZNET_SS: TEENSY.8 (8/TX3), U2.SS (NSS)

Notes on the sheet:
568-7397-1-ND


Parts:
X5, X6, X7_AUX: FAC64S

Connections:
+15V: X5.A31, X5.C31, X6.A31, X6.C31, X7_AUX.A31, X7_AUX.C31; also elsewhere on the board
-15V: X5.A30, X5.C30, X6.A30, X6.C30, X7_AUX.A30, X7_AUX.C30; also elsewhere on the board
A2: X5.A2, X6.A2, X7_AUX.A2
A5: X5.A5, X6.A5, X7_AUX.A5
A8: X5.A8, X6.A8, X7_AUX.A8
A9: X5.A9, X6.A9, X7_AUX.A9
A15: X5.A15, X6.A15, X7_AUX.A15
A16: X5.A16, X6.A16, X7_AUX.A16
A17: X5.A17, X6.A17, X7_AUX.A17
A18: X5.A18, X6.A18, X7_AUX.A18
A19: X5.A19, X6.A19, X7_AUX.A19
A20: X5.A20, X6.A20, X7_AUX.A20
A21: X5.A21, X6.A21, X7_AUX.A21
A22: X5.A22, X6.A22, X7_AUX.A22
A23: X5.A23, X6.A23, X7_AUX.A23
A27: X5.A27, X6.A27, X7_AUX.A27
A28: X5.A28, X6.A28, X7_AUX.A28
A29: X5.A29, X6.A29, X7_AUX.A29
C2: X5.C2, X6.C2, X7_AUX.C2
C5: X5.C5, X6.C5, X7_AUX.C5
C8: X5.C8, X6.C8, X7_AUX.C8
C9: X5.C9, X6.C9, X7_AUX.C9
C15: X5.C15, X6.C15, X7_AUX.C15
C16: X5.C16, X6.C16, X7_AUX.C16
C17: X5.C17, X6.C17, X7_AUX.C17
C18: X5.C18, X6.C18, X7_AUX.C18
C19: X5.C19, X6.C19, X7_AUX.C19
C20: X5.C20, X6.C20, X7_AUX.C20
C21: X5.C21, X6.C21, X7_AUX.C21
C22: X5.C22, X6.C22, X7_AUX.C22
C23: X5.C23, X6.C23, X7_AUX.C23
C27: X5.C27, X6.C27, X7_AUX.C27
C28: X5.C28, X6.C28, X7_AUX.C28
C29: X5.C29, X6.C29, X7_AUX.C29
D0: X5.A10, X6.A10, X7_AUX.A10; also elsewhere on the board
D1: X5.C10, X6.C10, X7_AUX.C10; also elsewhere on the board
D2: X5.A11, X6.A11, X7_AUX.A11; also elsewhere on the board
D3: X5.C11, X6.C11, X7_AUX.C11; also elsewhere on the board
GND: X5.A1, X5.A25, X5.C1, X5.C25, X6.A1, X6.A25, X6.C1, X6.C25, X7_AUX.A1, X7_AUX.A25, X7_AUX.C1, X7_AUX.C25; also elsewhere on the board
GPIO0: X5.A3, X6.A3, X7_AUX.A3; also elsewhere on the board
GPIO1: X5.C3, X6.C3, X7_AUX.C3; also elsewhere on the board
GPIO2: X5.A4, X6.A4, X7_AUX.A4; also elsewhere on the board
GPIO3: X5.C4, X6.C4, X7_AUX.C4; also elsewhere on the board
GPIO4: X5.A6, X6.A6, X7_AUX.A6; also elsewhere on the board
GPIO5: X5.C6, X6.C6, X7_AUX.C6; also elsewhere on the board
GPIO6: X5.A7, X6.A7, X7_AUX.A7; also elsewhere on the board
GPIO7: X5.C7, X6.C7, X7_AUX.C7; also elsewhere on the board
HV: X5.A26, X5.C26, X6.A26, X6.C26, X7_AUX.A26, X7_AUX.C26
HV_INTERLOCK: X5.A24, X5.C24, X6.A24, X6.C24, X7_AUX.A24, X7_AUX.C24; also elsewhere on the board
I2C_SCL: X5.C14, X6.C14, X7_AUX.C14; also elsewhere on the board
I2C_SDA: X5.A14, X6.A14, X7_AUX.A14; also elsewhere on the board
SPI_CS5: X5.C12; also elsewhere on the board
SPI_CS6: X6.C12; also elsewhere on the board
SPI_CS7_AUX: X7_AUX.C12; also elsewhere on the board
SPI_MISO: X5.C13, X6.C13, X7_AUX.C13; also elsewhere on the board
SPI_MOSI: X5.A13, X6.A13, X7_AUX.A13; also elsewhere on the board
SPI_SCLK: X5.A12, X6.A12, X7_AUX.A12; also elsewhere on the board
VREF: X5.A32, X5.C32, X6.A32, X6.C32, X7_AUX.A32, X7_AUX.C32; also elsewhere on the board



Board: 4 copper layers, 134.6 x 129.8 mm, 25 parts (21 on the bottom side), 77 nets.

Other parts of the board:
U$1, U$4: JQI_LOGO_NEGATIVE-SILKSCREEN
U$3: BACKPLN-PROTO

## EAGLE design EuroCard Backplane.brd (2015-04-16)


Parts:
X1, X2, X3, X4, X5, X6, X7, X8: FAC64S

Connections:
A1: X1.A1, X2.A1, X3.A1, X4.A1, X5.A1, X6.A1, X7.A1, X8.A1
A2: X1.A2, X2.A2, X3.A2, X4.A2, X5.A2, X6.A2, X7.A2, X8.A2
A3: X1.A3, X2.A3, X3.A3, X4.A3, X5.A3, X6.A3, X7.A3, X8.A3
A4: X1.A4, X2.A4, X3.A4, X4.A4, X5.A4, X6.A4, X7.A4, X8.A4
A5: X1.A5, X2.A5, X3.A5, X4.A5, X5.A5, X6.A5, X7.A5, X8.A5
A6: X1.A6, X2.A6, X3.A6, X4.A6, X5.A6, X6.A6, X7.A6, X8.A6
A7: X1.A7, X2.A7, X3.A7, X4.A7, X5.A7, X6.A7, X7.A7, X8.A7
A8: X1.A8, X2.A8, X3.A8, X4.A8, X5.A8, X6.A8, X7.A8, X8.A8
A9: X1.A9, X2.A9, X3.A9, X4.A9, X5.A9, X6.A9, X7.A9, X8.A9
A10: X1.A10, X2.A10, X3.A10, X4.A10, X5.A10, X6.A10, X7.A10, X8.A10
A11: X1.A11, X2.A11, X3.A11, X4.A11, X5.A11, X6.A11, X7.A11, X8.A11
A12: X1.A12, X2.A12, X3.A12, X4.A12, X5.A12, X6.A12, X7.A12, X8.A12
A13: X1.A13, X2.A13, X3.A13, X4.A13, X5.A13, X6.A13, X7.A13, X8.A13
A14: X1.A14, X2.A14, X3.A14, X4.A14, X5.A14, X6.A14, X7.A14, X8.A14
A15: X1.A15, X2.A15, X3.A15, X4.A15, X5.A15, X6.A15, X7.A15, X8.A15
A16: X1.A16, X2.A16, X3.A16, X4.A16, X5.A16, X6.A16, X7.A16, X8.A16
A17: X1.A17, X2.A17, X3.A17, X4.A17, X5.A17, X6.A17, X7.A17, X8.A17
A18: X1.A18, X2.A18, X3.A18, X4.A18, X5.A18, X6.A18, X7.A18, X8.A18
A19: X1.A19, X2.A19, X3.A19, X4.A19, X5.A19, X6.A19, X7.A19, X8.A19
A20: X1.A20, X2.A20, X3.A20, X4.A20, X5.A20, X6.A20, X7.A20, X8.A20
A21: X1.A21, X2.A21, X3.A21, X4.A21, X5.A21, X6.A21, X7.A21, X8.A21
A22: X1.A22, X2.A22, X3.A22, X4.A22, X5.A22, X6.A22, X7.A22, X8.A22
A23: X1.A23, X2.A23, X3.A23, X4.A23, X5.A23, X6.A23, X7.A23, X8.A23
A24: X1.A24, X2.A24, X3.A24, X4.A24, X5.A24, X6.A24, X7.A24, X8.A24
A25: X1.A25, X2.A25, X3.A25, X4.A25, X5.A25, X6.A25, X7.A25, X8.A25
A26: X1.A26, X2.A26, X3.A26, X4.A26, X5.A26, X6.A26, X7.A26, X8.A26
A27: X1.A27, X2.A27, X3.A27, X4.A27, X5.A27, X6.A27, X7.A27, X8.A27
A28: X1.A28, X2.A28, X3.A28, X4.A28, X5.A28, X6.A28, X7.A28, X8.A28
A29: X1.A29, X2.A29, X3.A29, X4.A29, X5.A29, X6.A29, X7.A29, X8.A29
A30: X1.A30, X2.A30, X3.A30, X4.A30, X5.A30, X6.A30, X7.A30, X8.A30
A31: X1.A31, X2.A31, X3.A31, X4.A31, X5.A31, X6.A31, X7.A31, X8.A31
A32: X1.A32, X2.A32, X3.A32, X4.A32, X5.A32, X6.A32, X7.A32, X8.A32
C1: X1.C1, X2.C1, X3.C1, X4.C1, X5.C1, X6.C1, X7.C1, X8.C1
C2: X1.C2, X2.C2, X3.C2, X4.C2, X5.C2, X6.C2, X7.C2, X8.C2
C3: X1.C3, X2.C3, X3.C3, X4.C3, X5.C3, X6.C3, X7.C3, X8.C3
C4: X1.C4, X2.C4, X3.C4, X4.C4, X5.C4, X6.C4, X7.C4, X8.C4
C5: X1.C5, X2.C5, X3.C5, X4.C5, X5.C5, X6.C5, X7.C5, X8.C5
C6: X1.C6, X2.C6, X3.C6, X4.C6, X5.C6, X6.C6, X7.C6, X8.C6
C7: X1.C7, X2.C7, X3.C7, X4.C7, X5.C7, X6.C7, X7.C7, X8.C7
C8: X1.C8, X2.C8, X3.C8, X4.C8, X5.C8, X6.C8, X7.C8, X8.C8
C9: X1.C9, X2.C9, X3.C9, X4.C9, X5.C9, X6.C9, X7.C9, X8.C9
C10: X1.C10, X2.C10, X3.C10, X4.C10, X5.C10, X6.C10, X7.C10, X8.C10
C11: X1.C11, X2.C11, X3.C11, X4.C11, X5.C11, X6.C11, X7.C11, X8.C11
C12: X1.C12, X2.C12, X3.C12, X4.C12, X5.C12, X6.C12, X7.C12, X8.C12
C13: X1.C13, X2.C13, X3.C13, X4.C13, X5.C13, X6.C13, X7.C13, X8.C13
C14: X1.C14, X2.C14, X3.C14, X4.C14, X5.C14, X6.C14, X7.C14, X8.C14
C15: X1.C15, X2.C15, X3.C15, X4.C15, X5.C15, X6.C15, X7.C15, X8.C15
C16: X1.C16, X2.C16, X3.C16, X4.C16, X5.C16, X6.C16, X7.C16, X8.C16
C17: X1.C17, X2.C17, X3.C17, X4.C17, X5.C17, X6.C17, X7.C17, X8.C17
C18: X1.C18, X2.C18, X3.C18, X4.C18, X5.C18, X6.C18, X7.C18, X8.C18
C19: X1.C19, X2.C19, X3.C19, X4.C19, X5.C19, X6.C19, X7.C19, X8.C19
C20: X1.C20, X2.C20, X3.C20, X4.C20, X5.C20, X6.C20, X7.C20, X8.C20
C21: X1.C21, X2.C21, X3.C21, X4.C21, X5.C21, X6.C21, X7.C21, X8.C21
C22: X1.C22, X2.C22, X3.C22, X4.C22, X5.C22, X6.C22, X7.C22, X8.C22
C23: X1.C23, X2.C23, X3.C23, X4.C23, X5.C23, X6.C23, X7.C23, X8.C23
C24: X1.C24, X2.C24, X3.C24, X4.C24, X5.C24, X6.C24, X7.C24, X8.C24
C25: X1.C25, X2.C25, X3.C25, X4.C25, X5.C25, X6.C25, X7.C25, X8.C25
C26: X1.C26, X2.C26, X3.C26, X4.C26, X5.C26, X6.C26, X7.C26, X8.C26
C27: X1.C27, X2.C27, X3.C27, X4.C27, X5.C27, X6.C27, X7.C27, X8.C27
C28: X1.C28, X2.C28, X3.C28, X4.C28, X5.C28, X6.C28, X7.C28, X8.C28
C29: X1.C29, X2.C29, X3.C29, X4.C29, X5.C29, X6.C29, X7.C29, X8.C29
C30: X1.C30, X2.C30, X3.C30, X4.C30, X5.C30, X6.C30, X7.C30, X8.C30
C31: X1.C31, X2.C31, X3.C31, X4.C31, X5.C31, X6.C31, X7.C31, X8.C31
C32: X1.C32, X2.C32, X3.C32, X4.C32, X5.C32, X6.C32, X7.C32, X8.C32


Board: 4 copper layers, 426.7 x 129.8 mm, 9 parts (0 on the bottom side), 64 nets.

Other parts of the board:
U$1: BACKPLANE

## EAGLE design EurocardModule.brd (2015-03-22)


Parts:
CP1, CP2: 220uF; PANASONIC_F
J1: VG64P
L1, L2: FERRITE; 0805; PARTNO 445-5223-1-ND

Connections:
+15V: J1.A31, J1.C31, L2.2
-15V: J1.A30, J1.C30, L1.1
GND: CP1.+, CP2.-, J1.A1, J1.C1
V+: CP2.+, L2.1
V-: CP1.-, L1.2


Board: 2 copper layers, 160.0 x 100.0 mm, 5 parts (0 on the bottom side), 5 nets.

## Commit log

2015-03-16 Started repository
    Files so far consist of 8 connectors and mechanical mounting holes
    [EuroCard Backplane.brd, EuroCard Backplane.sch]
2015-03-22 Added starter schematic for Eurocard modules
    [EurocardModule.brd, EurocardModule.sch]
2015-04-16 Add a couple dimensions to board
    [EuroCard Backplane.brd, EuroCard Backplane.sch]
2015-04-16 Stub for test backplane
    [EurocardBackplane-test.brd, EurocardBackplane-test.sch]
2015-04-17 Mostly-routed test board with teensy, WIZNET, and vref.
    [EurocardBackplane-test.brd, EurocardBackplane-test.sch]
2015-04-19 routing and layout of test board done
    [EurocardBackplane-test.brd, EurocardBackplane-test.sch]
2015-04-19 Added Gerber files for eurocard-backplane-test
2015-10-13 updated test backplane
    [EurocardBackplane-test.brd, EurocardBackplane-test.sch]
2015-10-13 Started V1.0
    [EurocardBackplane-V1_0.brd, EurocardBackplane-V1_0.sch]
2015-10-14 Halfway done adding more connectors
    [EurocardBackplane-V1_0.brd, EurocardBackplane-V1_0.sch]
2015-10-16 Incremental progress
    [EurocardBackplane-V1_0.brd, EurocardBackplane-V1_0.sch]
2015-10-19 Version 1.0 board layout pretty much done
    [EurocardBackplane-V1_0.brd, EurocardBackplane-V1_0.sch]
2015-11-17 Started Version 2: Better digital line shielding, microcontroller moved off board
    [EurocardBackplane-V2_0.brd, EurocardBackplane-V2_0.sch]
2015-11-19 Added note to include QR code on silkscreen for production run
    [EurocardBackplane-V2_0.brd]
2015-11-19 Made short version of backplane for digital noise testing
    [EurocardBackplane-V2_0-short.brd, EurocardBackplane-V2_0-short.sch]
2016-01-30 Stub schematic for MCU backplane board
    Really just for noise testing at this point; should be modified when
    we're ready to make the final deal.
    [EurocardBackplane-MCU.brd, EurocardBackplane-MCU.sch]
